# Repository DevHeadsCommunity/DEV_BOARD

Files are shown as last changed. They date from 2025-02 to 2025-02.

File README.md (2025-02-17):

# STM32 Cortex-M0 Development Board

## Project overview
Develop a low-cost development board featuring an STM32 Cortex-M0 microcontroller with integrated sensors, display, and debugging capabilities. 
The board will support USB debugging and UART communication, making it suitable for prototyping applications requiring motion sensing and environmental data collection.

## Key Features

1. Microcontroller: STM32F072C8T6 (Cortex-M0, USB Full-Speed 2.0)

2. Sensors:

i. LSM6DS3 (6-axis IMU: Gyroscope + Accelerometer)

ii. QMC5883L (Magnetometer)

iii. Temperature sensor

3. Display Options:

i. 1x 7-segment display or 4x LEDs (whichever is cheaper)

4. Onboard Debugging:

i. USB-to-UART via CH340T

5. Supports automatic bootloader mode via DTR/RTS

6. Expansion & Connectivity:

i. Multiple GPIOs for prototyping

ii. Space for additional headers

## Design and Development

The hardware design is being developed using KiCad, focusing on creating a compact and cost-effective PCB layout. 
This project does not include firmware development but provides a solid hardware platform for future software implementation.

## Components needed
1. STM32F072C8T6 Microcontroller: Core processing unit

2. LSM6DS3 + QMC5883L: Motion sensing and magnetometer

3. 7-segment display / LEDs: Visual output

4. CH340T USB-to-UART: Serial communication and flashing support

5. Supporting Components: Resistors, capacitors, headers, etc.

##   PCB Design Plan

1. Schematic Design

i. Connect STM32F072C8T6 with sensors, display, and USB debugging interface.

ii. Ensure power regulation and signal integrity.

2. PCB Layout

i. Optimize component placement for a compact and efficient design.

ii. Route signals carefully to minimize interference.

3. Prototype & Testing

i. Manufacture PCB and verify electrical connections.

ii. Validate power delivery and communication between components.

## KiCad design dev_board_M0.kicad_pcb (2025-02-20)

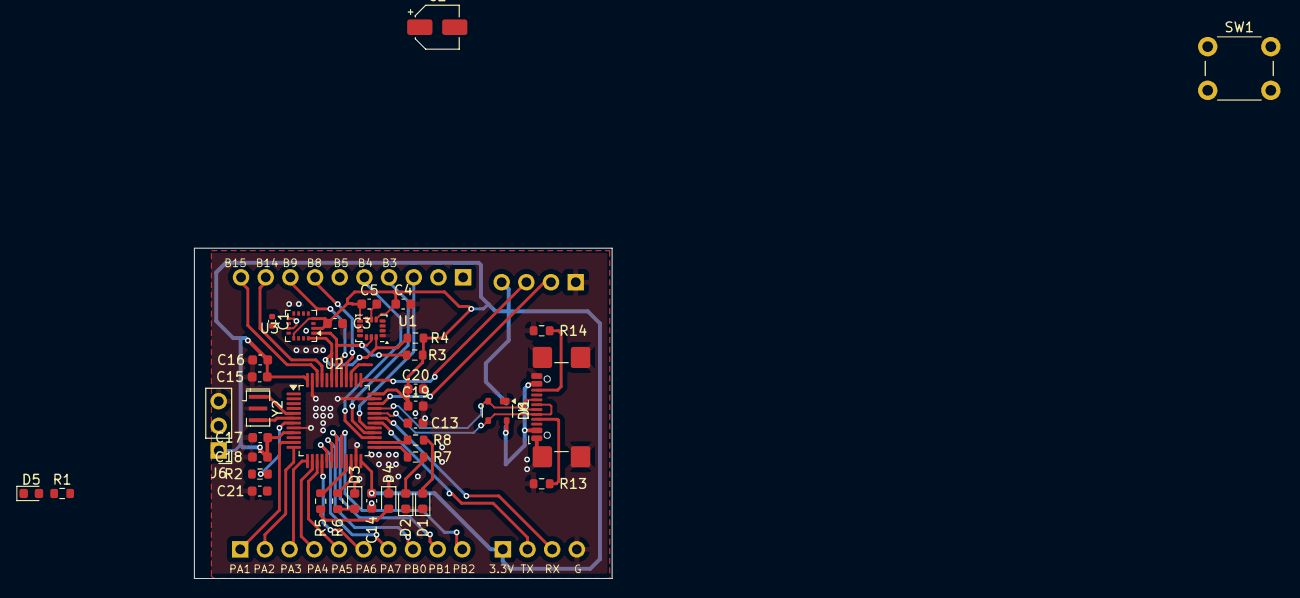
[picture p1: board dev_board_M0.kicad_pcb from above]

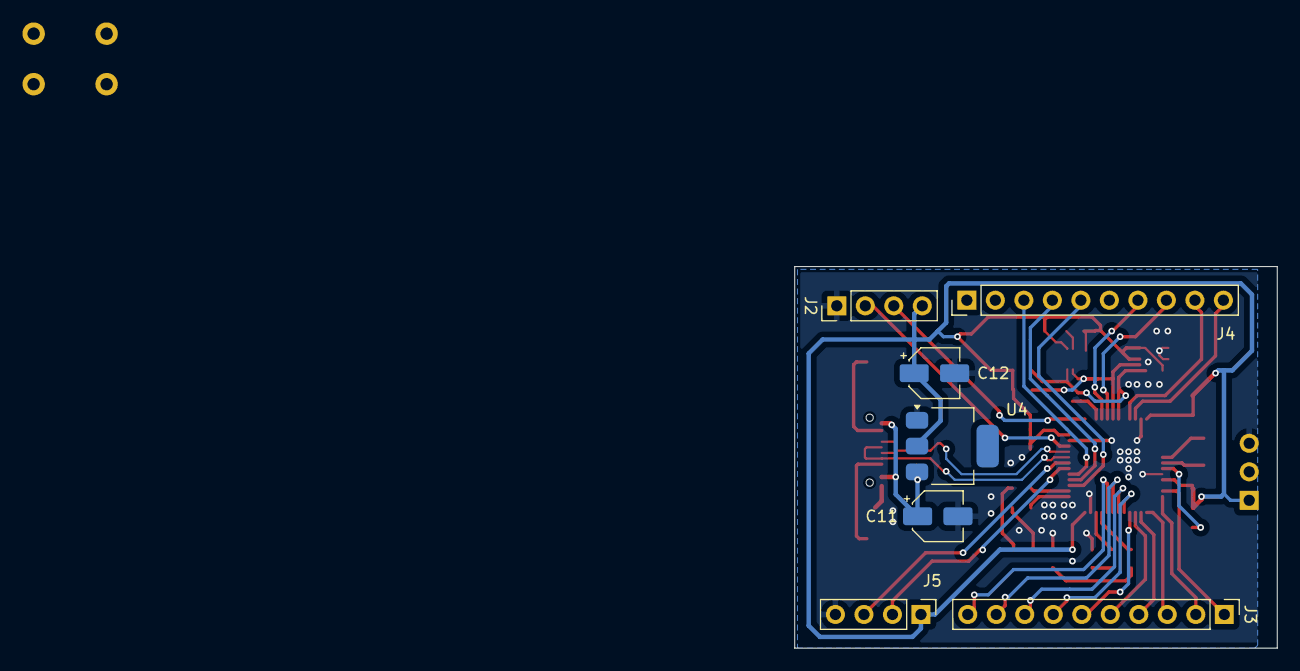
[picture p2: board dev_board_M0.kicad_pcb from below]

Board: 2 copper layers, 43.0 x 34.0 mm, 44 parts (7 on the bottom side), 47 nets.

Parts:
C1: 0.22uF; C_0402_1005Metric
C2: 4.7uF; CP_Elec_4x4.5
C3, C4, C5, C13, C14, C15, C19: 0.1uf; C_0603_1608Metric
C11: 10uF,50v; CP_Elec_4x5.4
C12: 22uF,50v; CP_Elec_4x5.4
C16, C20: 4.7uf; C_0603_1608Metric
C17: 10nf; C_0603_1608Metric
C18, C21: 1uf; C_0603_1608Metric
D1, D2, D3, D4: LED; LED_0603_1608Metric
D5: RED; LED_0603_1608Metric
D6: PRTR5V0U2X; SOT-143
J1: USB_C_Receptacle_USB2.0_16P; USB_C_Receptacle_GCT_USB4110
J2: DEBUGGER; PinHeader_1x04_P2.54mm_Vertical
J3: PIN_HEADER1; PinHeader_1x10_P2.54mm_Vertical
J4: PIN_HEADER2; PinHeader_1x10_P2.54mm_Vertical
J5: USART1; PinHeader_1x04_P2.54mm_Vertical
J6: DFU; PinHeader_1x03_P2.54mm_Vertical
R1, R2, R5, R6, R7, R8: 5k1; R_0603_1608Metric
R3, R4: 10K; R_0603_1608Metric
R13, R14: 5.1k; R_0603_1608Metric
SW1: SW_MEC_5E; SW_PUSH_6mm
U1: LSM6DS3; LGA-14_3x2.5mm_P0.5mm_LayoutBorder3x4y
U2: STM32F072C8Tx; LQFP-48_7x7mm_P0.5mm
U3: HMC5883L; LGA-16_3x3mm_P0.5mm
U4: TLV1117-33IDCYR; SOT-223
Y2: 8MhZ; Resonator_SMD_Murata_CSTxExxV-3Pin_3.0x1.1mm

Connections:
+3.3V: C3.1, C4.1, C5.1, C12.1, C13.1, C14.1, C15.1, C16.1, C17.1, C18.1, C19.1, C20.1, J2.4, J5.1, J6.1, R1.2, R2.2, R3.2, R4.2, U1.5 (VDDIO), U1.8 (VDD), U2.9 (VDDA), U2.24 (VDD), U2.36 (VDDIO2), U2.48 (VDD), U3.2 (VDD), U3.4 (S1), U3.13 (VDDIO), U4.2 (VO)
+5V: C11.1, D6.4 (VCC), J1.A4 (VBUS), J1.A9 (VBUS), J1.B4 (VBUS), J1.B9 (VBUS), U4.3 (VI)
/NRST: C21.1, R2.1, SW1.1, U2.7 (NRST)
/PA1: J3.1, U2.11 (PA1)
/PA2: J3.2, U2.12 (PA2)
/PA3: J3.3, U2.13 (PA3)
/PA4: J3.4, U2.14 (PA4)
/PA5: J3.5, U2.15 (PA5)
/PA6: J3.6, U2.16 (PA6)
/PA7: J3.7, U2.17 (PA7)
/PA8: J4.3, U2.29 (PA8)
/PA11: D6.3 (I/O2), J1.A7 (D-), J1.B7 (D-), U2.32 (PA11)
/PA12: D6.2 (I/O1), J1.A6 (D+), J1.B6 (D+), U2.33 (PA12)
/PB0: J3.8, U2.18 (PB0)
/PB1: J3.9, U2.19 (PB1)
/PB2: J3.10, U2.20 (PB2)
/PB3: J4.6, U2.39 (PB3)
/PB4: J4.7, U2.40 (PB4)
/PB5: J4.8, U2.41 (PB5)
/PB8: J4.9, U2.45 (PB8)
/PB9: J4.10, U2.46 (PB9)
/PB14: J4.5, U2.27 (PB14)
/PB15: J4.4, U2.28 (PB15)
/SCL: R3.1, U1.13 (SCL), U2.42 (PB6), U3.1 (SCL)
/SDA: R4.1, U1.14 (SDA), U2.43 (PB7), U3.16 (SDA)
/SWDIO: J2.2, U2.34 (PA13)
/SWLCK: J2.3, U2.37 (PA14)
/USART1_RX: J5.3, U2.31 (PA10)
/USART1_TX: J5.2, U2.30 (PA9)
GND: C2.2, C3.2, C4.2, C5.2, C11.2, C12.2, C13.2, C14.2, C15.2, C16.2, C17.2, C18.2, C19.2, C20.2, C21.2, D1.1 (K), D2.1 (K), D3.1 (K), D4.1 (K), D5.1 (K), D6.1 (GND), J1.A1 (GND), J1.A12 (GND), J1.B1 (GND), J1.B12 (GND), J1.S1 (SHIELD), J2.1, J5.4, J6.3, R13.1, R14.1, SW1.2, U1.1 (SDO/SA0), U1.2 (SDX), U1.6 (GND), U1.7 (GND), U2.8 (VSSA), U2.23 (VSS), U2.35 (VSS), U2.47 (VSS), U3.9 (GND@1), U3.11 (GND@2), U4.1 (GND), Y2.2
unnamed: D1.2 (A), R8.2
unnamed: D2.2 (A), R7.2
unnamed: D3.2 (A), R6.2
unnamed: D4.2 (A), R5.2
unnamed: D5.2 (A), R1.1
unnamed: J1.A5 (CC1), R13.2
unnamed: J1.B5 (CC2), R14.2
unnamed: J6.2, U2.44 (BOOT0)
unnamed: R5.1, U2.21 (PB10)
unnamed: R6.1, U2.22 (PB11)
unnamed: R7.1, U2.25 (PB12)
unnamed: R8.1, U2.26 (PB13)
unnamed: U2.5 (PF0), Y2.1
unnamed: U2.6 (PF1), Y2.3
unnamed: C2.1, U3.10 (C1)
unnamed: C1.2, U3.12 (SETC)
unnamed: C1.1, U3.8 (SETP)

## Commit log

2025-02-17 created the design file
    [dev_board_M0.kicad_pcb, dev_board_M0.kicad_sch]
2025-02-18 Wired gyro/accel and magnetometer
    [dev_board_M0.kicad_sch]
2025-02-20 Finished up the schematic
    [dev_board_M0-B_Cu.gbr, dev_board_M0-B_Mask.gbr, dev_board_M0-B_Paste.gbr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]
